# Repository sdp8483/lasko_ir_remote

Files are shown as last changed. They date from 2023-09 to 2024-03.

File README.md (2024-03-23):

# Lasko IR Remote

A cloned IR remote to control a Lasko pedestal fan.

Lasko Remotes

# Signal Decoding
The remote sends signals to the fan using an infrared LED. This IR LED is connected to the GPIO of a microcontroller so that when the GPIO pin is pulled low the IR LED is turned on.

## Carrier Frequency
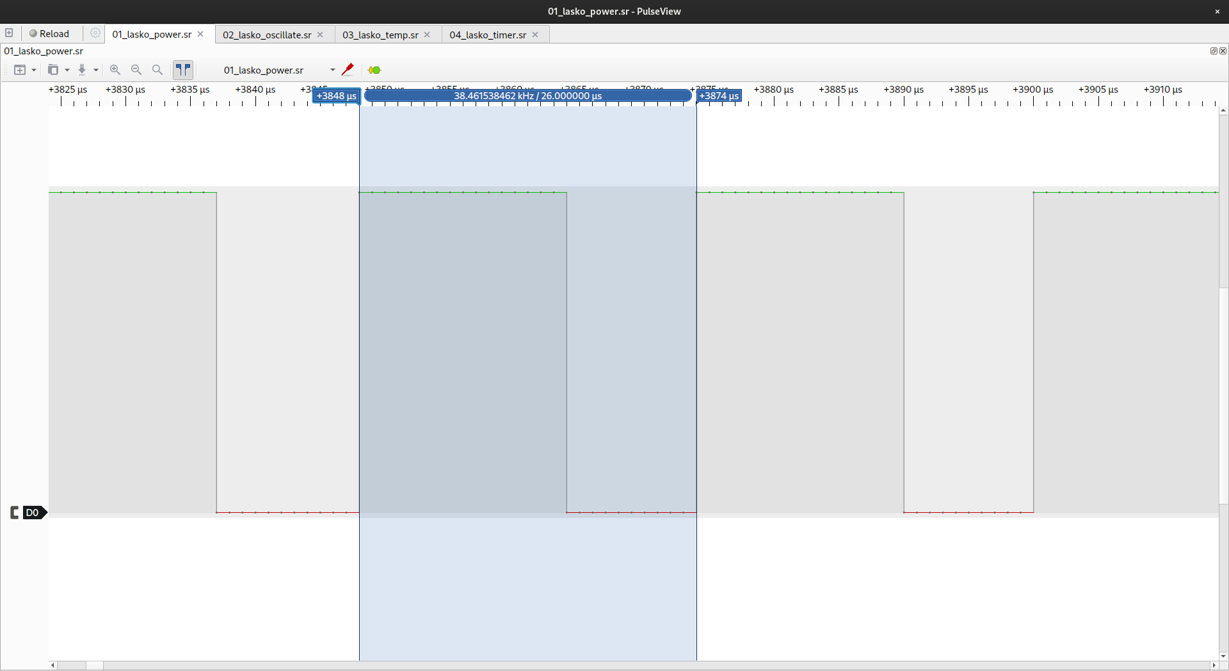
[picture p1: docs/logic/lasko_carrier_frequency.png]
Logic Capture of Carrier Frequency

The IR LED sends the signals using a carrier frequency of 38kHz. This seems to be a popular frequency for most consumer IR remotes. Bits are sent as a duration of pulsing the IR LED at the carrier frequency followed by a period of no IR. All bits are 1680us long.

## Signal Bit Value of One
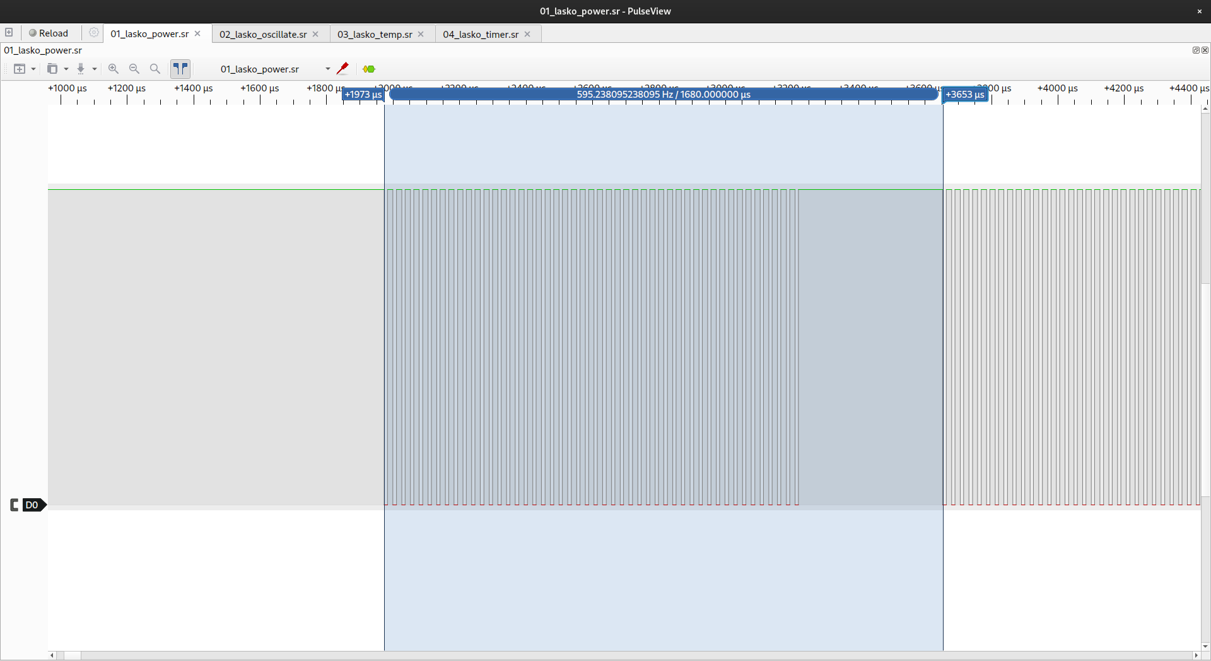
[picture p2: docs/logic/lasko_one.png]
Logic Capture of One

I'm calling the above bit as having a value of `one`. I have no way of knowing if the remote and fan consider this value to be a `one` but it doesn't matter since this designation is used only as a shortcut in my firmware to encode the signals. This bit is 1680us long with 1246us of IR LED pulsing followed by no IR for the remainder of the bit.

## Signal Bit Value of Zero
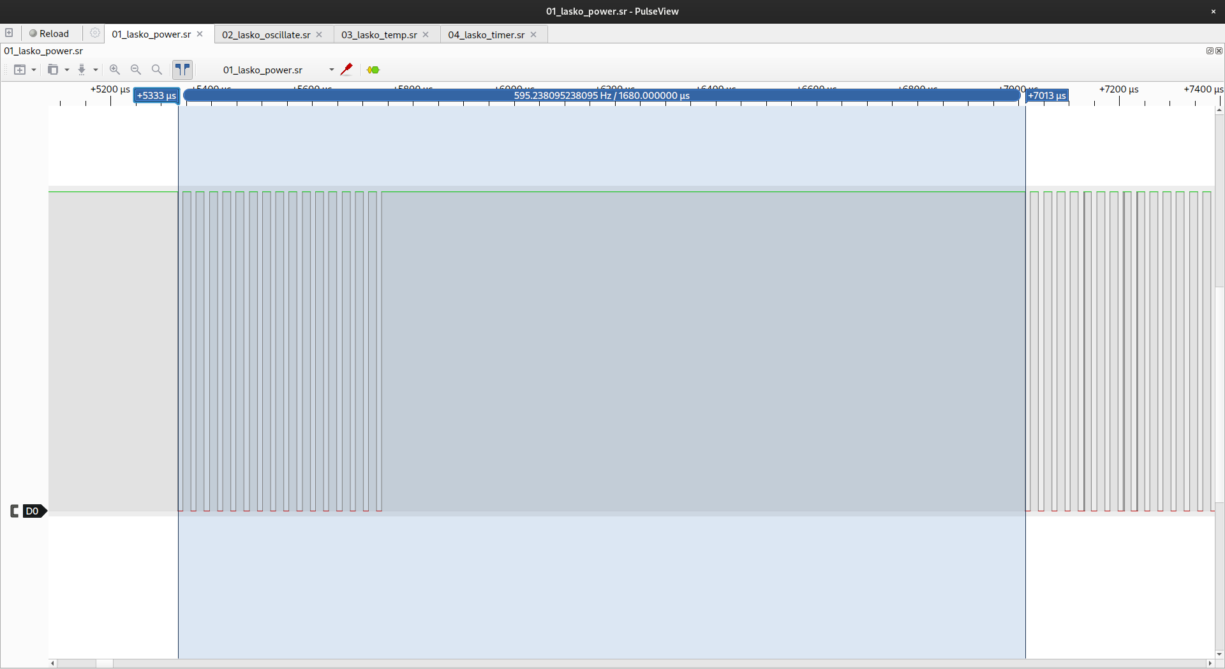
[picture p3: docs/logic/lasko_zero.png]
Logic Capture of Zero

The above bit has a value of `zero`. Again this bit is 1680us long with 404us of IR LED pulsing followed by no IR for the remainder of the bit.

## Power Signal
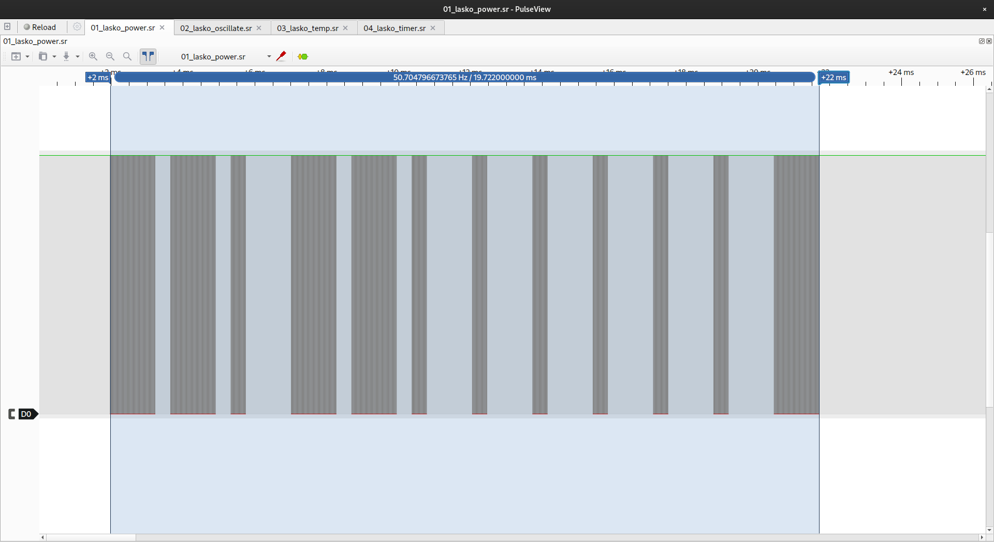
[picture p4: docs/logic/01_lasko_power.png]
Logic Capture of Power Signal

The remote strings together the `one` and `zero` bit values to send out commands. Following the bit value convention outlined above the logic capture of the power signal is `0b110110000001`. All signals are 12 bits long and repeat 4 times with a delay of 7107us between repeats. The power signal from the remote will turn on the fan if it is off and decrement through the four fan speeds with each press until turning the fan is off again.

## Oscillate Signal
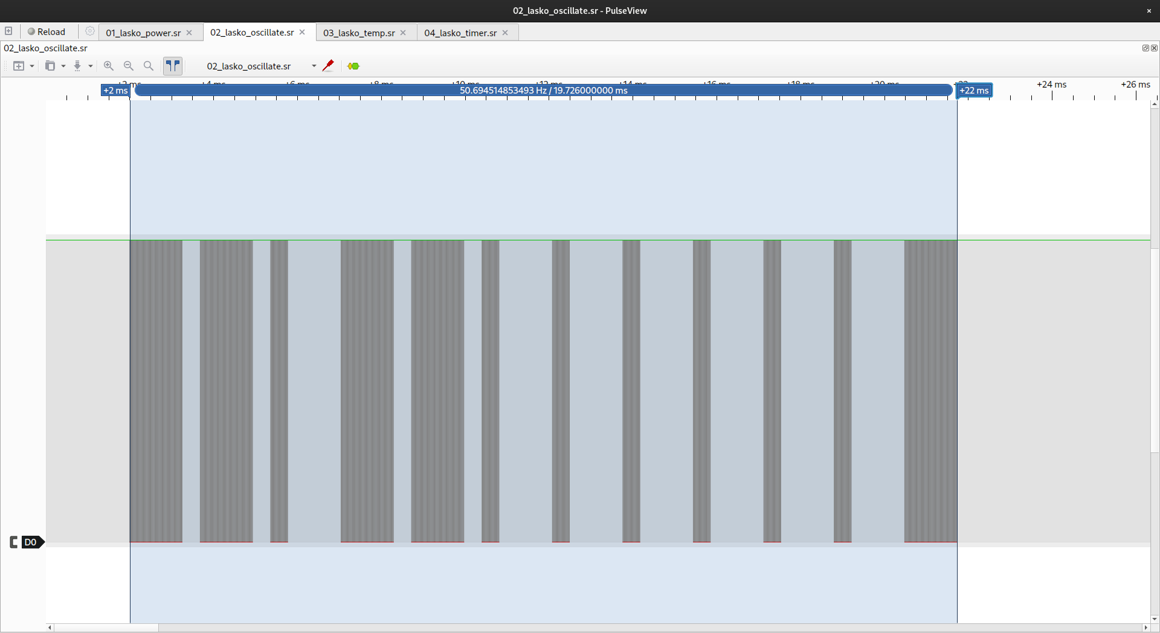
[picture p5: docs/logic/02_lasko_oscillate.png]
Logic Capture of Oscillate Signal

The oscillate signal is `0b110110000010`. The oscillate signal will enable and disable the oscillation of the fan.

## Temperature Signal
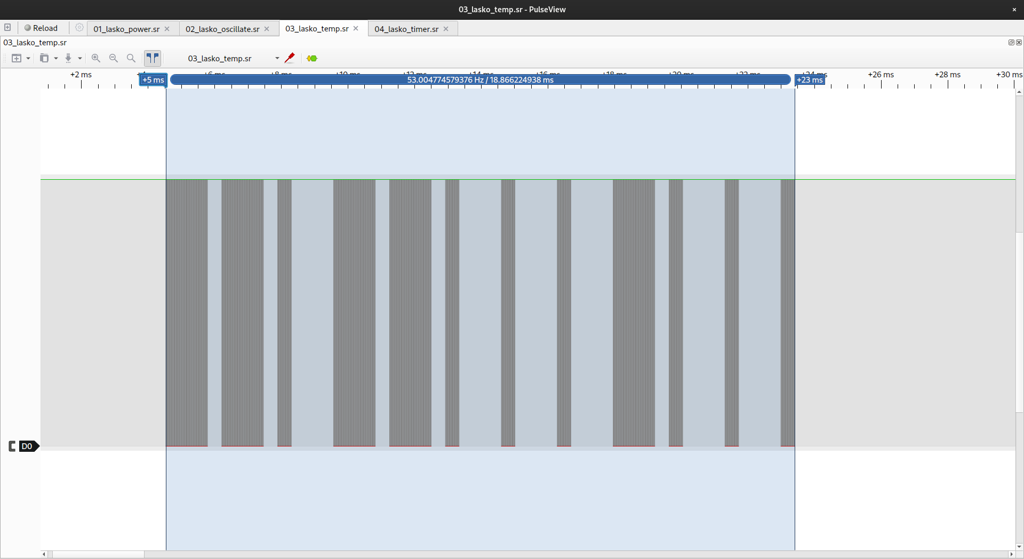
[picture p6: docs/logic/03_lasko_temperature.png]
Logic Capture of Temperature Signal

The temperature signal is `0b110110010000`. This signal is used to set a turn off temperature for the fan from 60F to 80F in 5F increments. If the ambient temperature drops below this setting the fan will turn off.

## Timer Signal
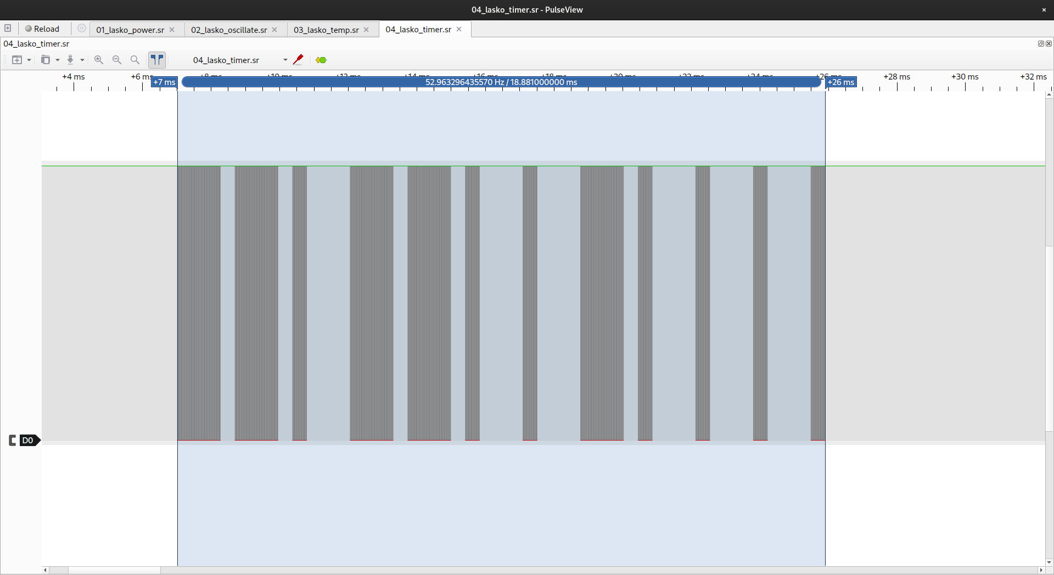
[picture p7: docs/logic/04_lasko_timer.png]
Logic Capture of Timer Signal

The timer signal is `0b110110001000`. This signal sets a timer to turn the fan off. Interestingly the timer value is displayed as a binary value. There are LEDs for 1, 2, and 4 hours on the fan. By pressing the timer button the timer will increment from 1 to 7 hours.

# Schematic
There is nothing ground breaking about the circuit I came up with. The heavy lifting is done using my favorite microcontroller for small projects, the Attiny212. The hardest part about this circuit was finding what IR LED to use, I found 940nm to be the correct wavelength.

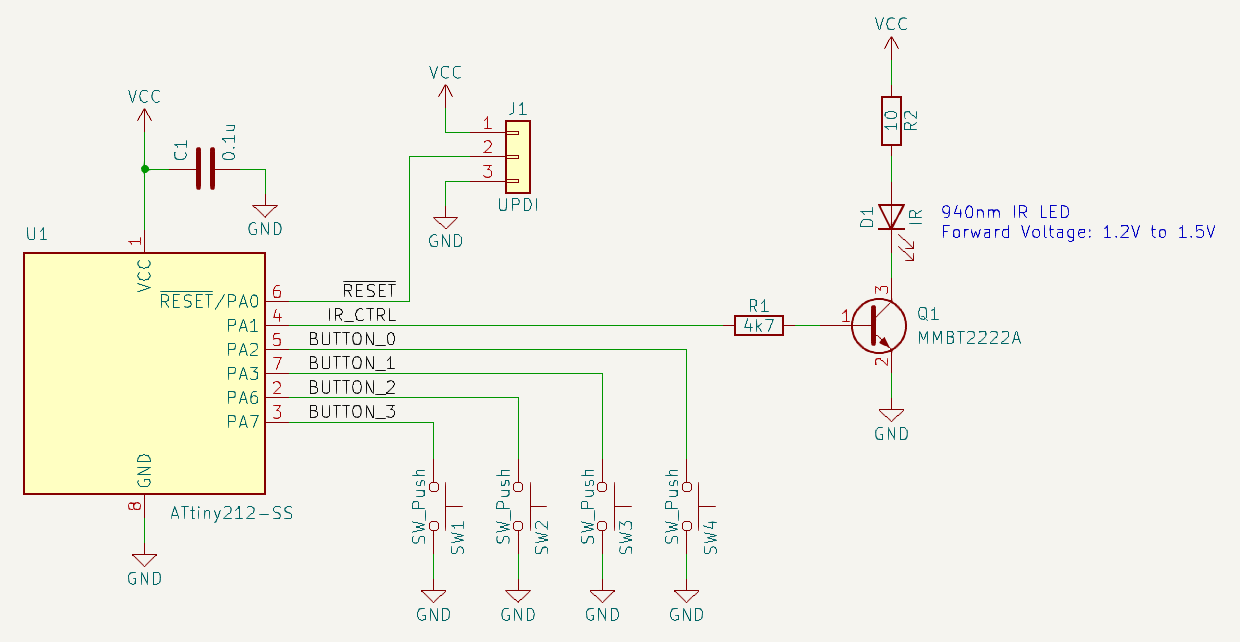
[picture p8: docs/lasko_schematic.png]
Clone Remote Schematic


# Firmware
The microcontroller spends much of its time asleep to save power. All four buttons are used as an interrupt to wake the Attiny212. The carrier frequency is generated using Timer A on the Attiny212. The timer ISR will toggle the IR LED for the required duration and then the IR LED will be turned off for the remainder of the bit. Again to save power the Attiny212 is allowed to sleep in between pulses. The full code can be found here: [firmware/scr/main.cpp](firmware/scr/main.cpp)

# PCB
Since I only wanted to make two extra remotes I decided to make the PCBs at home using my [CNC 3018 pro mill](https://samueldperry.com/cnc-3018-pro-router/).

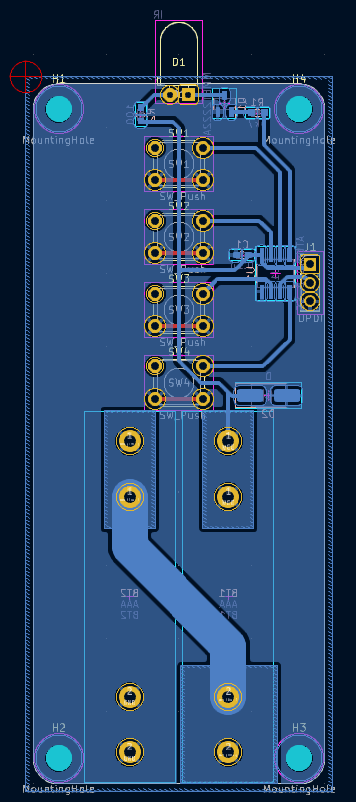
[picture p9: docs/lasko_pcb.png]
PCB in KiCAD


PCB Closeup

# Enclosure
For the enclosure I went with a 3D printed three piece design. The enclosure is held together with 10mm long M3 socket head bolts. I have threaded inserts to make battery changes easier.

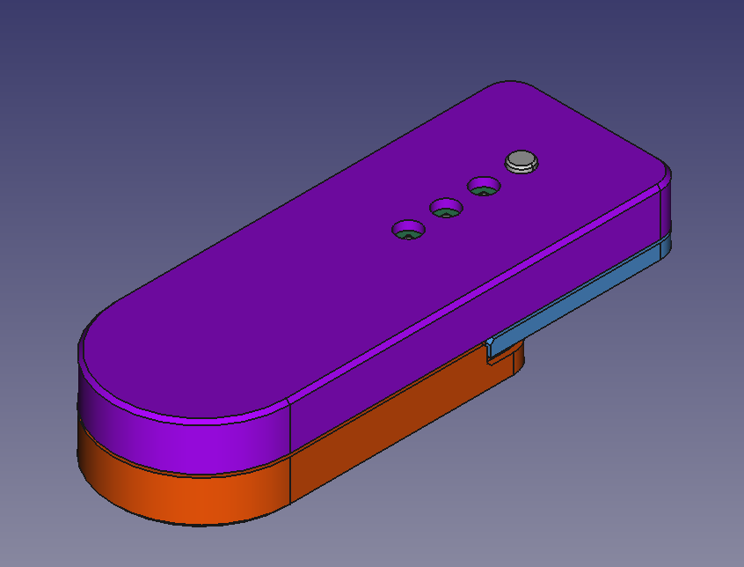
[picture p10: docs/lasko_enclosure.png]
Enclosure Render


Enclosure Closeup

# Conclusion
This was an easy project to make with the most difficult part being finding the correct wavelength of IR LED to use. I initially used a 850nm IR LED but I found that while the signal would be received by the fan, the remote had to be pointing directly at the fan and I had to be standing within arms reach for it to work. The 940nm IR LED was found to work much better.

The final hardest part of this project was that I completed this PCB and firmware about 6 months ago and only now have gotten around to writing this documentation up. I have forgotten much and have had to gloss over many of the details in this documentation.

Blog Post: https://samueldperry.com/2024/03/23/lasko-pedestal-fan-remote/

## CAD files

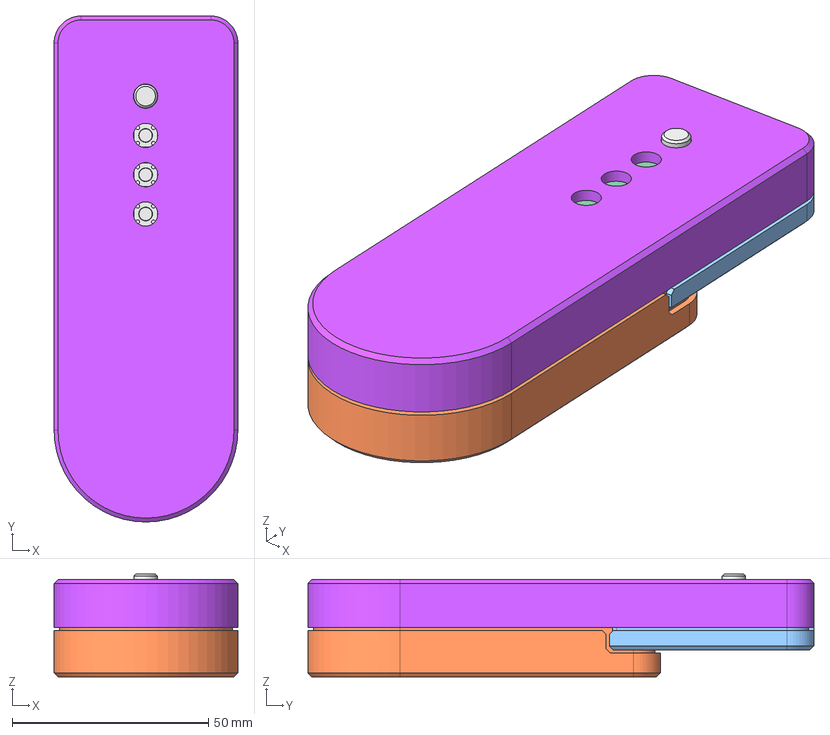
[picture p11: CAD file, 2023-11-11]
mechanical/assembly.FCStd
46.8 x 128.8 x 26.2 mm
Pcb_aece
SW1_SW_PUSH_6mm_h5mm_05eb81616619 x 4
D1_LED_D5.0mm_Horizontal_O1.27mm_Z3.0mm_IRGrey_566698dd2a7a
BK-82_sp x 2
BK-82_sp001 x 2
U1_SOIC_8_39x49mm_P127mm_04c5c029a4b3
R1_R_0603_1608Metric_b0138990e0ed x 2
C1_C_0603_1608Metric_9edfb1c5a845
D2_D_SMA_993c8eca7501
top
bottom_battery
bottom_upper
button

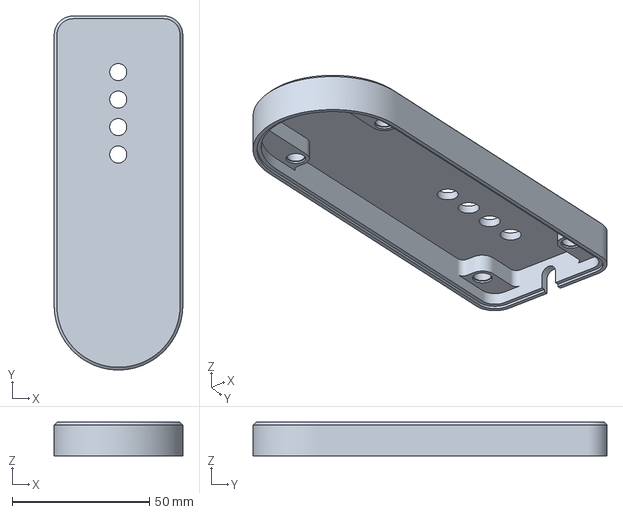
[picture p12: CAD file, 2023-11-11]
mechanical/3d_files/top.amf
46.8 x 128.8 x 12.2 mm

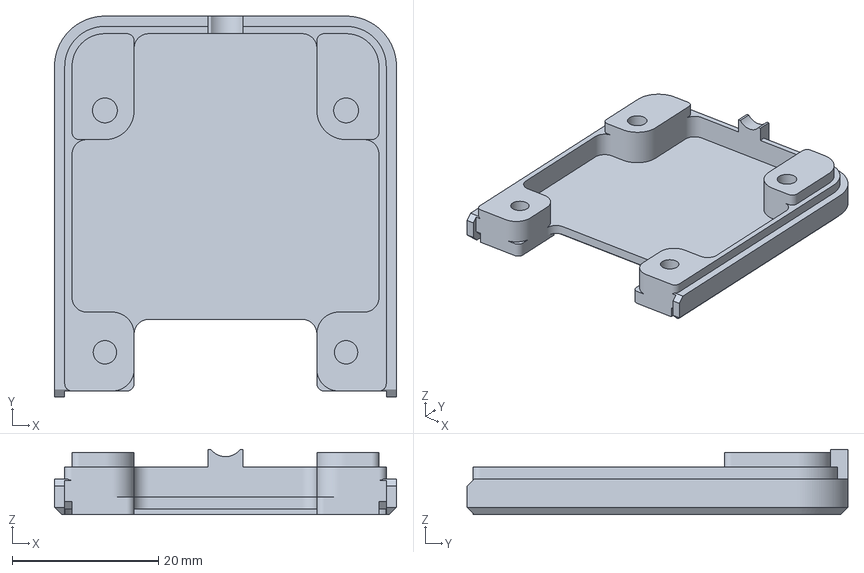
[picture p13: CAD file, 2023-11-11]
mechanical/3d_files/bottom_upper.amf
46.8 x 52.1 x 8.94 mm

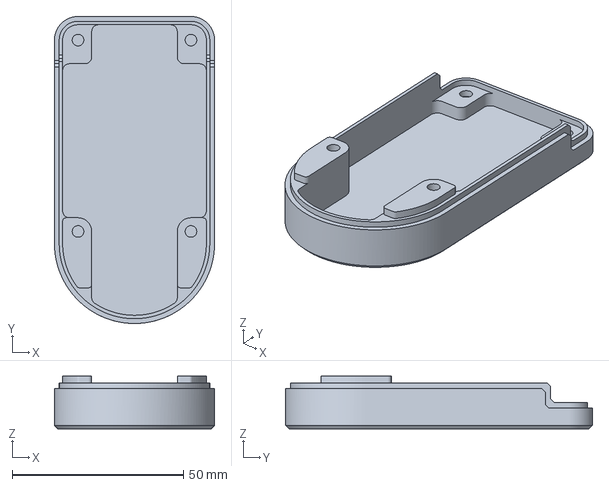
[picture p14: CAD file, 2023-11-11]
mechanical/3d_files/bottom_battery.amf
46.8 x 89.7 x 15.4 mm

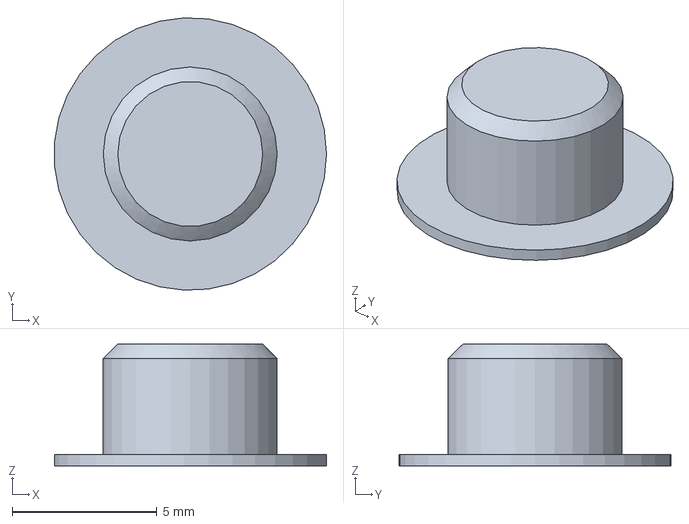
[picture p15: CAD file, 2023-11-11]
mechanical/3d_files/button.amf
9.38 x 9.39 x 4.20 mm

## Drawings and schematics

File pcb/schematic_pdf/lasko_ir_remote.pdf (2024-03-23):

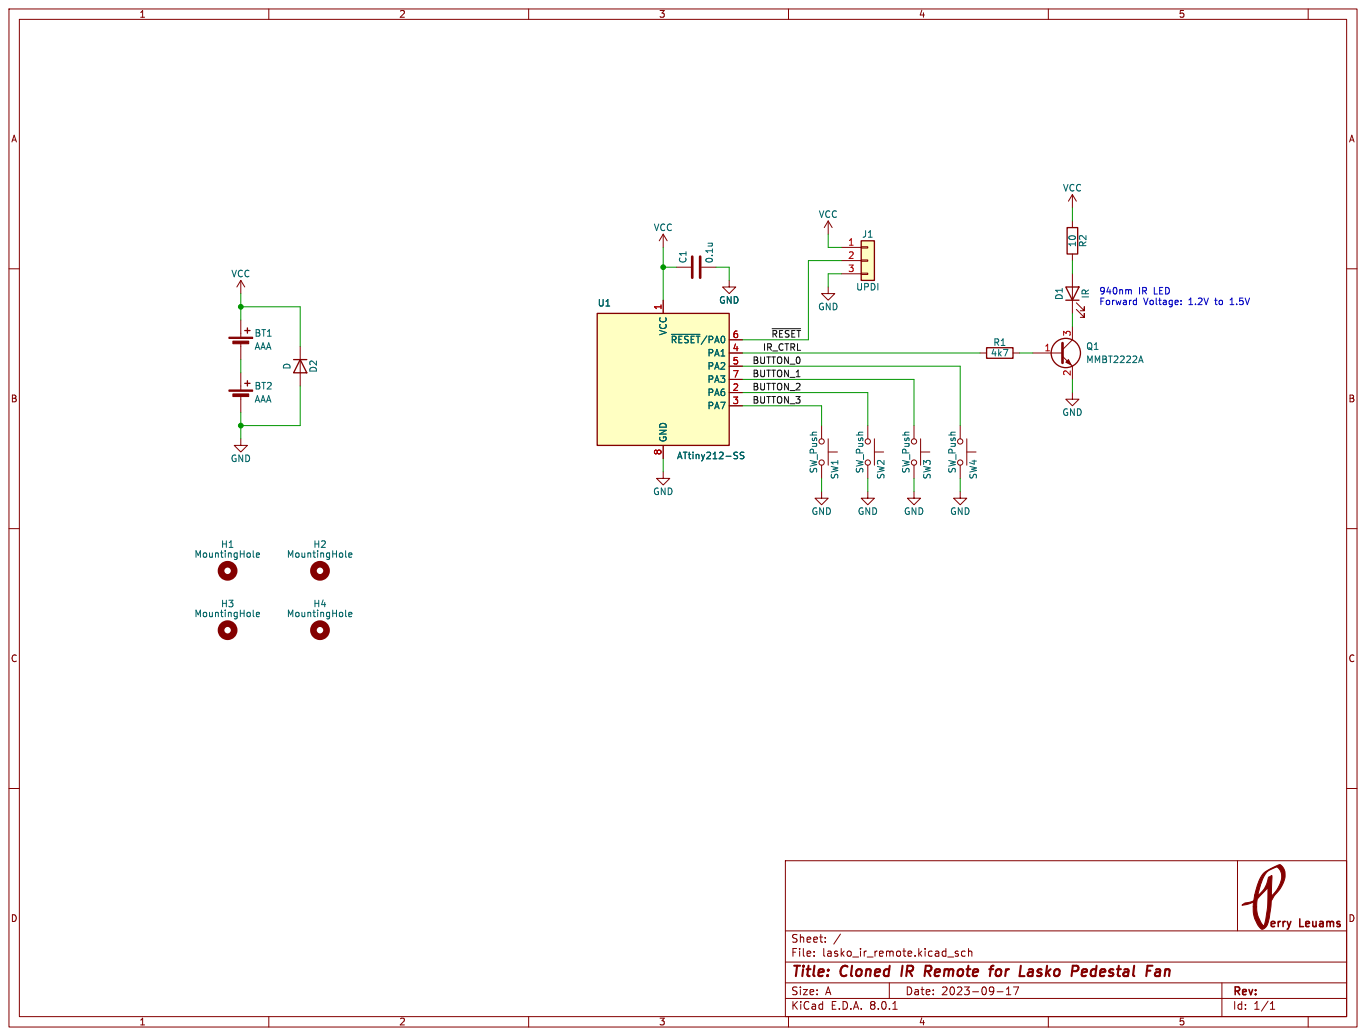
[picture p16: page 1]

H2 MountingHole H4 MountingHole H1 MountingHole GND

Id: 1/1 Title: Cloned IR Remote for Lasko Pedestal Fan

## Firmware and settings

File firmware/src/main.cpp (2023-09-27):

/* Includes ------------------------------------------------------------------ */
#include <avr/io.h>
#include <avr/interrupt.h>
#include <avr/sleep.h>
#include <avr/delay.h>
#include <stdint.h>

#include "clock.h"                                  /* set main clock based on platformio.ini f_cpu value */

/* Define -------------------------------------------------------------------- */
#define IR_CARRIER_FREQUENCY_HZ     38000   /* Hz, carrier frequency of IR signal */
#define IR_CARRIER_PERIOD_US        (1000000 / IR_CARRIER_FREQUENCY_HZ)
#define IR_BIT_DURATION_US          1680    /* useconds, spacing between bits */
#define IR_ONE_BIT_DURATION_US      1246    /* useconds, how long a '1' bit signal is on */
#define IR_ZERO_BIT_DURATION_US     404     /* useconds, how long a '0' bit signal is on */

#define IR_BIT_PULSES               int((IR_BIT_DURATION_US / IR_CARRIER_PERIOD_US) + 0.5) * 2
#define IR_ONE_BIT_PULSES           int((IR_ONE_BIT_DURATION_US / IR_CARRIER_PERIOD_US) + 0.5) * 2
#define IR_ONE_BIT_END_PULSES       (IR_BIT_PULSES - IR_ONE_BIT_PULSES)
#define IR_ZERO_BIT_PULSES          int((IR_ZERO_BIT_DURATION_US / IR_CARRIER_PERIOD_US) + 0.5) * 2
#define IR_ZERO_BIT_END_PULSES      (IR_BIT_PULSES - IR_ZERO_BIT_PULSES)

#define IR_REPEATS                  4       /* number of repeat transmissions */
#define IR_DELAY_BETWEEN_REPEATS_US 7107

#define TCA0_COUNTER_VALUE          int(((F_CPU / IR_CARRIER_FREQUENCY_HZ) / 2) + 0.5)  /* used to generate 38kHz, timer counts to this value */

#define BUTTON_DEBOUNCE_ms          50              /* minimum button delay when held down */

#define BUTTON_0_PIN                (1 << PIN2_bp)  /* button_0 net label from schematic */
#define BUTTON_1_PIN                (1 << PIN3_bp)  /* button_1 net label from schematic */
#define BUTTON_2_PIN                (1 << PIN6_bp)  /* button_2 net label from schematic */
#define BUTTON_3_PIN                (1 << PIN7_bp)  /* button_3 net label from schematic */

#define POWER_BUTTON                BUTTON_3_PIN    /* send power command to cycle though fan speeds */
#define OSCILLATE_BUTTON            BUTTON_2_PIN    /* send oscillate command to turn fuction on/off */
#define TIMER_BUTTON                BUTTON_1_PIN    /* send timer command to cycle through timer */
#define TEMPERATURE_BUTTON          BUTTON_0_PIN    /* send temperature command to cycle through temperatures */

#define POWER_COMMAND               0b110110000001  /* power command signal */
#define POWER_COMMAND_LEN           12              /* number of bits in power command signal */
#define OSCILLATE_COMMAND           0b110110000010  /* oscillate command signal */
#define OSCILLATE_COMMAND_LEN       12              /* number of bits in oscillate command signal */
#define TIMER_COMMAND               0b110110010000  /* timer command signal */
#define TIMER_COMMAND_LEN           12              /* number of bits in timer command signal */
#define TEMPERATURE_COMMAND         0b110110001000  /* temperature command signal */
#define TEMPERATURE_COMMAND_LEN     12              /* number of bits in temperature command signal */

/* Macro --------------------------------------------------------------------- */

/* Typedef ------------------------------------------------------------------- */
typedef enum buttons_t {
    POWER       = POWER_BUTTON,
    OSCILLATE   = OSCILLATE_BUTTON,
    TIMER       = TIMER_BUTTON,
    TEMPERATURE = TEMPERATURE_BUTTON,
    NONE        = 0
};

/* Globals ------------------------------------------------------------------- */
volatile buttons_t wake_button;  /* flag that is set on button ISR to signal to main code what button was pressed */

/* Function Prototypes ------------------------------------------------------- */
void ir_one_bit(void);
void ir_zero_bit(void);
void ir_sleep(void);
void ir_send(uint16_t cmd, int8_t len);
void button_wait_for_release(uint8_t button);

/* Main ---------------------------------------------------------------------- */
int main(void) {
    clock_init();   /* Set main clock frequency to value set in platformio.ini */

    /* setup buttons as inputs */
    PORTA.DIRCLR = (POWER_BUTTON | OSCILLATE_BUTTON | TIMER_BUTTON | TEMPERATURE_BUTTON);

    /* setup IR pin PA1 as output, WO1 from TCA0 */
    PORTA.DIRSET = 1 << PIN1_bp;

    /* for low power on unused pin set pullup, disable input buffer */
    PORTA.PIN0CTRL = ((1 << PORT_PULLUPEN_bp) | PORT_ISC_INPUT_DISABLE_gc);

    while(1) {
        /* setup button interrupts on low level, enable pullup */
        PORTA.PIN2CTRL = (PORT_ISC_LEVEL_gc | (1 << PORT_PULLUPEN_bp));
        PORTA.PIN3CTRL = (PORT_ISC_LEVEL_gc | (1 << PORT_PULLUPEN_bp));
        PORTA.PIN6CTRL = (PORT_ISC_LEVEL_gc | (1 << PORT_PULLUPEN_bp));
        PORTA.PIN7CTRL = (PORT_ISC_LEVEL_gc | (1 << PORT_PULLUPEN_bp));

        /* sleep until button press */
        set_sleep_mode(SLEEP_MODE_PWR_DOWN);
        sei();                  /* enable global interrupts */
        sleep_mode();           /* enable and sleep, wake here */

        /* disable button interrupts */
        PORTA.PIN2CTRL |= PORT_ISC_INTDISABLE_gc;
        PORTA.PIN3CTRL |= PORT_ISC_INTDISABLE_gc;
        PORTA.PIN6CTRL |= PORT_ISC_INTDISABLE_gc;
        PORTA.PIN7CTRL |= PORT_ISC_INTDISABLE_gc;

        /* setup timer A */
        TCA0.SINGLE.CTRLESET = TCA_SINGLE_CMD_RESET_gc;
        TCA0.SINGLE.CMP0 = TCA0_COUNTER_VALUE;
        TCA0.SINGLE.CTRLB = (1 << TCA_SINGLE_CMP1EN_bp)     /* enable compare 1, PA1 */
                            | TCA_SINGLE_WGMODE_FRQ_gc;     /* waveform mode, frequency */
        TCA0.SINGLE.INTCTRL = 1 << TCA_SINGLE_OVF_bp;       /* enable ISR when counter reaches TOP (CMP0 in waveform frequency mode) */
        TCA0.SINGLE.CTRLA = (TCA_SINGLE_CLKSEL_DIV1_gc      /* system clock */
                            | (1 << TCA_SINGLE_ENABLE_bp)); /* enable */

        /* send out IR signal based on button pressed */
        switch (wake_button) {
            case POWER:
                ir_send(POWER_COMMAND, POWER_COMMAND_LEN);
                button_wait_for_release(POWER_BUTTON);
                break;
            case OSCILLATE:
                ir_send(OSCILLATE_COMMAND, OSCILLATE_COMMAND_LEN);
                button_wait_for_release(OSCILLATE_BUTTON);
                break;
            case TIMER:
                ir_send(TIMER_COMMAND, TIMER_COMMAND_LEN);
                button_wait_for_release(TIMER_BUTTON);
                break;
            case TEMPERATURE:
                ir_send(TEMPERATURE_COMMAND, TEMPERATURE_COMMAND_LEN);
                button_wait_for_release(TEMPERATURE_BUTTON);
                break;
            default:
                break;
        }

        /* disable timer A */
        TCA0.SINGLE.CTRLA = (0 << TCA_SINGLE_ENABLE_bp);
    }
}

ISR(PORTA_PORT_vect) {
    cli();  /* disable interrupts */
    wake_button = (buttons_t) VPORTA.INTFLAGS;
    VPORTA.INTFLAGS = 0xff;   /* clear all button interrupts */
}

ISR(TCA0_OVF_vect) {
	/* The interrupt flag has to be cleared manually */
	TCA0.SINGLE.INTFLAGS = TCA_SINGLE_OVF_bm;
}

void ir_sleep(void) {
    set_sleep_mode(SLEEP_MODE_IDLE);
    sei();          /* enable global interrupts */
    sleep_mode();   /* enables sleep, sleeps cpu, wakes from sleep and disables */
}

void ir_one_bit(void) {
    PORTA.DIRSET = 1 << PIN1_bp;    /* set PA1 as output */
    for (uint8_t i=0; i< IR_ONE_BIT_PULSES; i++) {
        ir_sleep();
    }

    PORTA.OUTCLR = 1 << PIN1_bp;
    PORTA.DIRCLR = 1 << PIN1_bp;    /* disable PA1 output */

    for (uint8_t i=0; i< IR_ONE_BIT_END_PULSES; i++) {
        ir_sleep();
    }
}

void ir_zero_bit(void) {
    PORTA.DIRSET = 1 << PIN1_bp;    /* set PA1 as output */
    for (uint8_t i=0; i< IR_ZERO_BIT_PULSES; i++) {
        ir_sleep();
    }

    PORTA.OUTCLR = 1 << PIN1_bp;
    PORTA.DIRCLR = 1 << PIN1_bp;    /* disable PA1 output */

    for (uint8_t i=0; i< IR_ZERO_BIT_END_PULSES; i++) {
        ir_sleep();
    }
}

void ir_send(uint16_t cmd, int8_t len) {
    for (uint8_t j=0; j<IR_REPEATS; j++) {
        for (int8_t i=len; i>=0; i--) {
            if ((cmd >> i) & 1) {
                ir_one_bit();
            } else {
                ir_zero_bit();
            }
        }

        _delay_us(IR_DELAY_BETWEEN_REPEATS_US);
    }
}

void button_wait_for_release(uint8_t button) {
    while (!(PORTA.IN & button)) {
        _delay_ms(BUTTON_DEBOUNCE_ms);
    }
}

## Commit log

2023-09-19 pcb layout
    [lasko_ir_remote.kicad_pcb, lasko_ir_remote.kicad_sch]
2023-09-19 export gerbers
    [lasko_ir_remote-B_Cu.gbr, lasko_ir_remote-Edge_Cuts.gbr, lasko_ir_remote-job.gbrjob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]
2023-09-20 increase clearance for pcb mill
    [lasko_ir_remote.kicad_pcb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]
2023-09-27 low power sleep, clear port interrupt
2023-09-27 only set pin interrupts in while loop, no repeats
2023-10-07 change ir LED resistor to 10R from 100R
    [lasko_ir_remote.kicad_sch]
2023-11-10 case redesign started
    [assembly.FCStd]
2023-11-11 v2 case
    [assembly.FCStd]
2023-11-11 remove V1 files
    [buttons.amf, case-bottom.amf, case-top.amf]
2023-11-11 V2 case files
    [bottom_battery.amf, bottom_upper.amf, button.amf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]
2023-11-11 modified battery and bottom to print without supports
    [assembly.FCStd, bottom_battery.amf, bottom_upper.amf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]
2024-03-23 export schma PDF
    [lasko_ir_remote.kicad_sch]
2024-03-23 update to kicad 8
    [lasko_ir_remote.kicad_pcb]
